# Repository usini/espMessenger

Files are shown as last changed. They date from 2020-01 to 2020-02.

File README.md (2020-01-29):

An 8x8 Matrix WiFi Display
--------------------------
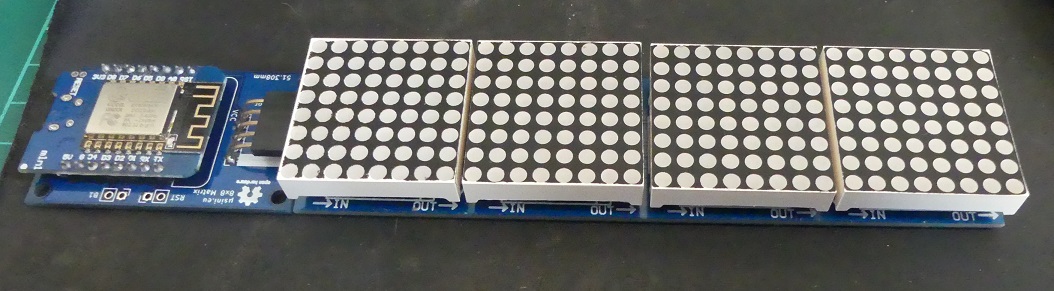
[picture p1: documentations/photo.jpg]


# Features
* Responsive Web Interface
* Simple Web Request to send Message (ex: http://espmessenger/message/hello send hello)
* Accentuated characters supports
* Localization Support (French / English as for now)
* WiFiManager configuration (Nb of devices / Password and Username)
* Basic HTTP Authentication
* Discoverable using Netbios / Bonjour / SSDP
* Web Update

# Libraries used
* MD_MAX72xx
* MD_Parola
* ArduinoJSON (v6)
* WiFiManager

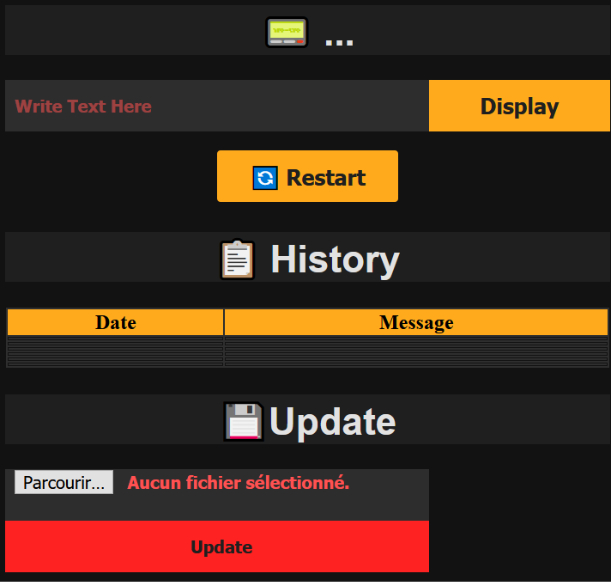
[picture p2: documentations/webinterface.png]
Web Interface


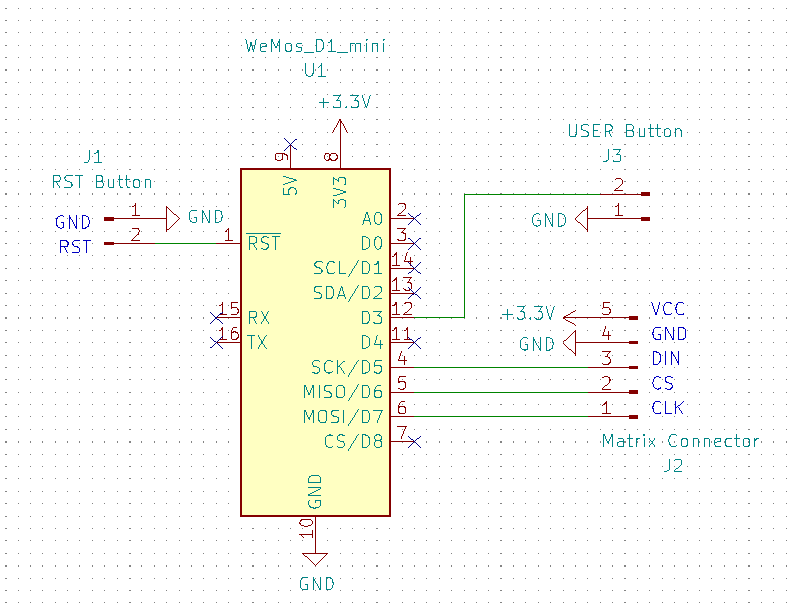
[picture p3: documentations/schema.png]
Schematics


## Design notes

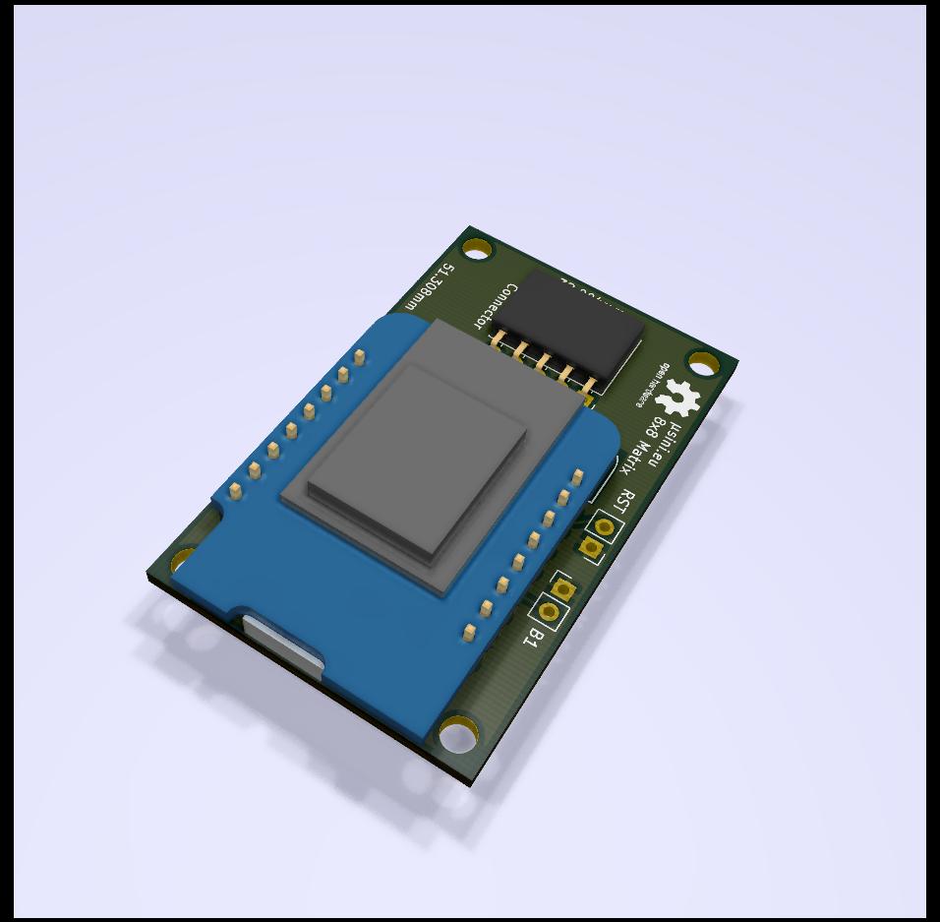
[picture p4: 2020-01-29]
documentations/esp8266_8x8MatrixLed.jpg

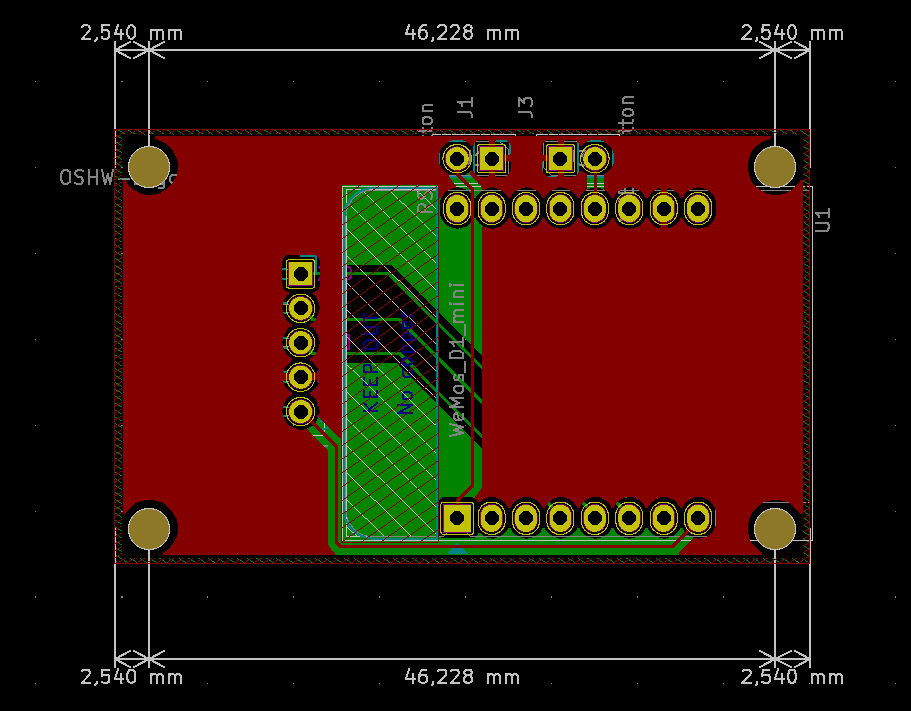
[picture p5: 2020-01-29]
documentations/pcb.png

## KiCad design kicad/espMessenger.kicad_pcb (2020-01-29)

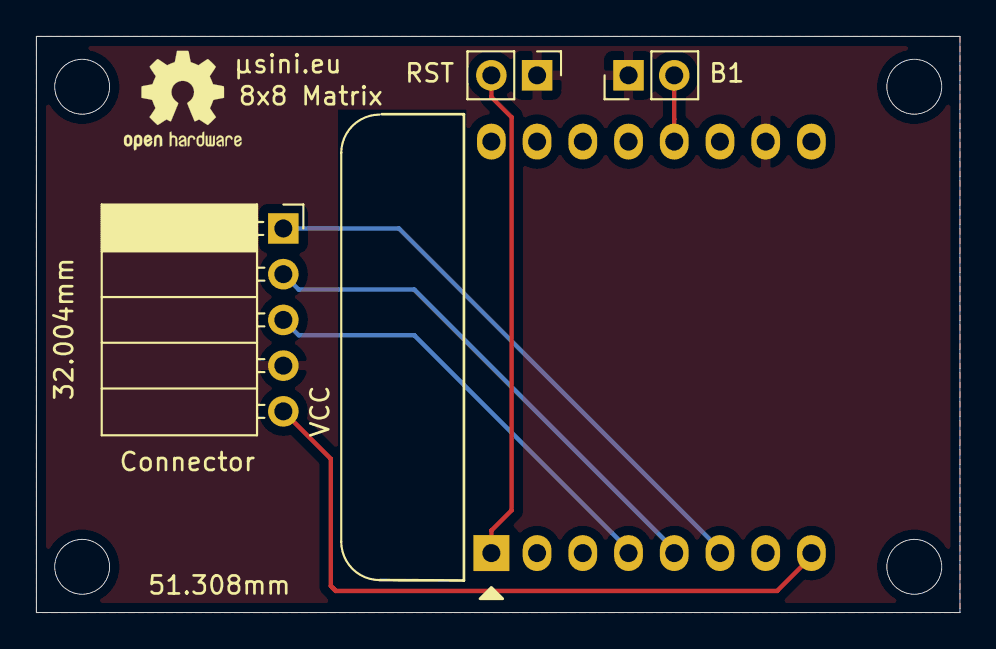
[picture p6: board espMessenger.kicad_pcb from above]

Board: 2 copper layers, 51.3 x 32.0 mm, 4 parts (0 on the bottom side), 7 nets.

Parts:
Connector: Matrix Connector; PinSocket_1x05_P2.54mm_Horizontal
J1: RST Button; PinHeader_1x02_P2.54mm_Vertical
J3: USER Button; PinHeader_1x02_P2.54mm_Vertical
U1: WeMos_D1_mini; WEMOS_D1_mini_light_no_female_connectors

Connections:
+3V3: Connector.5, U1.8
GND: Connector.4, J1.1, J3.1, U1.10
unnamed: J1.2, U1.1
unnamed: Connector.1, U1.6
unnamed: Connector.2, U1.5
unnamed: Connector.3, U1.4
unnamed: J3.2, U1.12

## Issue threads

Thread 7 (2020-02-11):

Button RESET WIFI on long press

maditnerd, 2020-02-11:

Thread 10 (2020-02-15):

Restart button doesn't display correctly on smartphone

maditnerd, 2020-02-15:

Closed 2020-02-16.

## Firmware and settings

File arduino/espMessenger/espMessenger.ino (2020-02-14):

/*
  ESPMessenger
  Connected Text Matrix for ESP8266
  By µsini
  Licence : MIT
  https://github.com/usini/espMessenger

  Library required:
  --> MD_MAX72xx (matrix.h)
  --> MD_Parola (matrix.h)
  --> ArduinoJSON (v6) (settings.h / web.h)
  --> WiFiManager (settings.h)
*/

//#include "lang/en.h"
#include "lang/fr.h"

#include "settings.h"
#include "matrix.h"
#include "web.h"
#include "banner.h"

const int LED = D4;

void setup() {
  Serial.begin(74880);
  pinMode(LED, OUTPUT);
  digitalWrite(LED, LOW);

  introBanner();
  startWiFiManager();

  initMatrix();
  matrixText((char*)settings.name, true);
  digitalWrite(LED, HIGH);

  setHostname();
  webStart(); // Start WebServer
  connectionBanner();
}

void loop() {
  webUpdate();
  MDNS.update(); // Manage Bonjour Name
}

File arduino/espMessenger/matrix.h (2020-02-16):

/* Mini Matrix Manager
  By Rémi Sarrailh <@m4dnerd>
  Licence : MIT
  UTF8 to Extended Ascii : https://playground.arduino.cc/Main/Utf8ascii/
*/


#include "fonts/Parola_Fonts_data.h" //Ascii Extended Font
#include <Ticker.h> //Parralel Manager

// PCB PINS
#define CLK_PIN   D7  // or SCK
#define CS_PIN    D6  // or SS
#define DATA_PIN  D5  // or MOSI
// ALT PINS
/*
  #define CLK_PIN   D5  // or SCK
  #define DATA_PIN  D6  // or MOSI
  #define CS_PIN    D7  // or SS
*/

#define HARDWARE_TYPE MD_MAX72XX::FC16_HW
#define CHAR_SPACING  1 // pixels between characters
#define BUF_SIZE  1024
#define CHAR_LIMIT 280
Ticker matrixManager;
bool needScrolling = true;

char curMessage[BUF_SIZE];
char newMessage[BUF_SIZE];
bool newMessageAvailable = false;
static byte c1;  // Last character buffer

MD_Parola* matrix;

//Scroll curMessage on Matrix (if newMessage change update curMessage)
void matrixUpdate() {
  if (needScrolling) {
    if (matrix->displayAnimate())
    {
      if (newMessageAvailable)
      {
        strcpy(curMessage, newMessage);
        newMessageAvailable = false;
      }
      matrix->displayReset();
    }
  } else {
    matrix->displayAnimate();
  }
}

void resetScrolling() {
  matrix->setInvert(settings.invert);
  matrix->setPause(settings.pause);
  matrix->setIntensity(settings.intensity);
  matrix->displayScroll(curMessage, settings.textPosition, settings.effectIn, settings.speed);
  matrix->setTextEffect(settings.effectIn, settings.effectOut);
}


//Initialize Matrix
void initMatrix() {

  //Serial.println(settings.devices);
  matrix = new MD_Parola(HARDWARE_TYPE, DATA_PIN, CLK_PIN, CS_PIN, settings.devices);
  //Settings Matrix
  matrix->begin();
  matrix->displayClear();
  matrix->displaySuspend(false);
  matrix->setFont(ExtASCII);
  resetScrolling();
  matrixManager.attach_ms(10, matrixUpdate);
}




// Convert UTF8 to Extended Ascii (byte by byte)
byte utf8ascii(byte ascii) {
  if ( ascii < 128 ) // Standard ASCII-set 0..0x7F handling
  { c1 = 0;
    return ( ascii );
  }

  // get previous input
  byte last = c1;   // get last char
  c1 = ascii;       // remember actual character
  switch (last)     // conversion depending on first UTF8-character
  { case 0xC2: return  (ascii);  break;
    case 0xC3: return  (ascii | 0xC0);  break;
    case 0x82: if (ascii == 0xAC) return (0x80);   // special case Euro-symbol
  }

  return  (0);                                     // otherwise: return zero, if character has to be ignored
}

// In Place conversion UTF8-string to Extended ASCII (ASCII is shorter!)
char* utf8ascii(char* s) {
  int k = 0;
  char c;
  for (int i = 0; i < strlen(s); i++)
  {
    c = utf8ascii(s[i]);
    if (c != 0)
      s[k++] = c;
  }
  s[k] = 0;
  return s;
}

// Convert UTF8 char pointer to Extended Ascii char pointer and copy it inside newMessage
void matrixText(char *message, bool instant) {
  if(!needScrolling){
    matrix->displayClear();
  }
  
  if (strlen(message) <= settings.devices + 1) {
    needScrolling = false;
  } else {
    needScrolling = true;
  }
  message = utf8ascii(message);
  //Serial.println(strlen(message));
  strcpy(newMessage, message);
  newMessageAvailable = true;
  if(needScrolling){
    if (instant) {
      matrix->displayClear();
      strcpy(curMessage, newMessage);
      resetScrolling();
    }
  } else {
    matrix->displayText(newMessage, PA_CENTER, 0, 0, PA_PRINT, PA_NO_EFFECT);
  }

  Serial.print(TEXT_MESSAGE);
  Serial.println(message);
  // } else {
  //  Serial.println(TEXT_MESSAGE_TOO_LONG);
  //}
}

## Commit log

2019-05-09 Settings page
    -- Settings page
    -- Save settings
    -- Reboot available (don't really works)
    -- No wait for Wifi Connection --> Crash because connecting simultanously to AP/Wifi
    -- U8glib added (not working correctly)
    [espMessenger.ino]
2019-05-12 Replace MD_MAX72XX with MD_Parolo (UTF-8 support)
    Minor tweak to Serial logging.
    [espMessenger.ino, matrix.h]
2019-05-12 Buffer overflow issue solved
    Remove unused debug in serial
    [matrix.h]
2019-05-14 Testing MQTT
    Long message dropped connection
    Can't change MQTT server address
    TODO: Switch to pubsubclient
2019-06-04 Add auth / Improve minify.py / seperated css/js
    Authentification cause a buffer overflow in SSL
    SSL is a bit too much for this board I think
    I'll keep the code for the esp32 port
2019-06-07 Add update field / Add comments / Move part of settings into settings_value
    --> Manage checkbox.
    Have some buffer overflow :-( code has some serious issues to inspect.
    May use an ESP32 instead.
    [espMessenger.ino, matrix.h]
2019-11-01 Complete rework
    --> Add WifiManager
    --> Change POST json request with REST request (/message/{message})
    --> Mandatory Basic Auth
    --> Possibility to setup nb of matrices
    --> Add FR/EN language choice
    [espMessenger.ino, matrix.h]
2020-01-29 Add schematics / pcb and Readme
    [esp8266_8x8MatrixLed-B_Cu.gbr, esp8266_8x8MatrixLed-B_Mask.gbr, esp8266_8x8MatrixLed-B_SilkS.gbr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]
2020-02-14 Add Speed/Intensity, some bugs fixes
    --> Need to add this changes to the english version, probably improve translation to avoid this issue.
    --> Add API to change Scroll effects and alignement and pause but didn't saved it as it is a bit not really useable for a simple scrolling text.
    [espMessenger.ino, matrix.h]
2020-02-15 Added node-red flow
2020-02-16 No scrolling if no necessary / bug translation fixes
    --> Translation is made using javascript to simplify code changes
    --> Version is display on serial/web (not automatic on web for now)
    --> Scrolling is disable if text can be display entirely
    --> Fix web bugs.
    [matrix.h]
